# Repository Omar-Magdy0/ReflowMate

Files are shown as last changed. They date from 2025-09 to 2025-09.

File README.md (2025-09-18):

# Reflow Mate

--- 

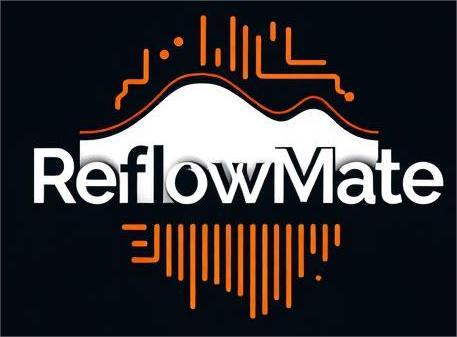
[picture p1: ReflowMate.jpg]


## Your open-source mate to PCB reflowing

#### Idea :
Your companion to pcb repair , assembly and testing , starting with Reflow capabilities...

To start small , grow big. current focus is mainly on providing :
* Digital Soldering iron support
* Hot air gun support
* 3d printable Accessories

#### Added :
* Hardware Core  (AC dimmers and related circuitry, DC Dimmer and related circuitry , Thermocouple interface , NTC interface , Expansion connectors)
#### Planned to be added :
* Fluid and mobile friendly web interface
* TFT LCD interface
* Modern and robust enclosure while keeping it small for mobility 

#### This project is a working in progress and still under testing and development

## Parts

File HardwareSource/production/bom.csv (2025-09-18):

Designator | Footprint | Quantity | Value | LCSC Part #
C1, C3, C5, C7 | 1206 | 4 | 1u-50V | C1848
C10, C9 | 1206 | 2 | 10u | C7432781
C11, C12, C13, C2, C4 | 1206 | 5 | 100n | C24497
D1 | SMA_L4.3-W2.6-LS5.2-RD | 1 | SS34_C8678 | C8678
D10 | DBS_L8.4-W6.4-P5.10-LS10.2-BL | 1 | DB107S_C525738 | C525738
D11, D5, D7, D9 | 1206 | 4 | LED | C965822
D2, D3 | 1206 | 2 | LED RED | C965822
D4, D6, D8 | SOD-123_L2.8-W1.8-LS3.7-RD | 3 | SD103AW_C181204 | C181204
L1 | IND-SMD_L7.1-W6.6_H5.0 | 1 | SMMS0650-680M | C2894721
Q1, Q2 | SOT-23-3_L2.9-W1.3-P0.95-LS2.4-BR | 2 | S9013_C402281 | C402281
Q3, Q4 | TO-220-3_Horizontal_TabDown | 2 | BT136-500 | C916781
Q5, Q6, Q7 | SOT-23_L2.9-W1.3-P1.90-LS2.4-BR | 3 | AO3400_C2938367 | C2938367
R1, R14, R16, R17, R18, R20, R21, R25, R26, R3, R7, R8 | 1206 | 12 | 10k | C17902
R10, R2, R4, R5, R6, R9 | 1206 | 6 | 1k | C2907440
R11, R12 | 1206 | 2 | 360 | C2907486
R13, R15, R19, R27 | 1206 | 4 | 680 | C2907528
R22, R23 | R_Axial_DIN0411_L9.9mm_D3.6mm_P7.62mm_Vertical | 2 | 33k (1W) | C20625284
R24, R28 | 1206 | 2 | 0 | C2907406
R29, R30 | 1206 | 2 | 4.7K | C137262
SW1, SW2 | SW-SMD_L6.0-W3.5-LS8.0 | 2 | TSB008A2526A | C2888456
T1, T2 | DIP-6_L8.5-W6.4-P2.54-LS7.6-BL | 2 | MOC3020M | C86911
U1 | WIFIM-SMD_39P-L25.5-W18.0-P1.27-BL | 1 | ESP32-WROOM-32D | C473012
U2 | SOIC-8_L5.0-W4.0-P1.27-LS6.0-BL | 1 | XL1509-5.0E1 | C61063
U3 | SOT-223-3_TabPin2_NOSILKSCREEN | 1 | AMS1117-3.3 | C347222
U4, U6 | SO-8_L4.9-W3.9-P1.27-LS5.9-BL | 2 | MAX31855KASA+T | C52028
U5 | SOP-4_L6.5-W4.6-P2.54-LS10.3-TL | 1 | EL817S1C(F) | C2912100

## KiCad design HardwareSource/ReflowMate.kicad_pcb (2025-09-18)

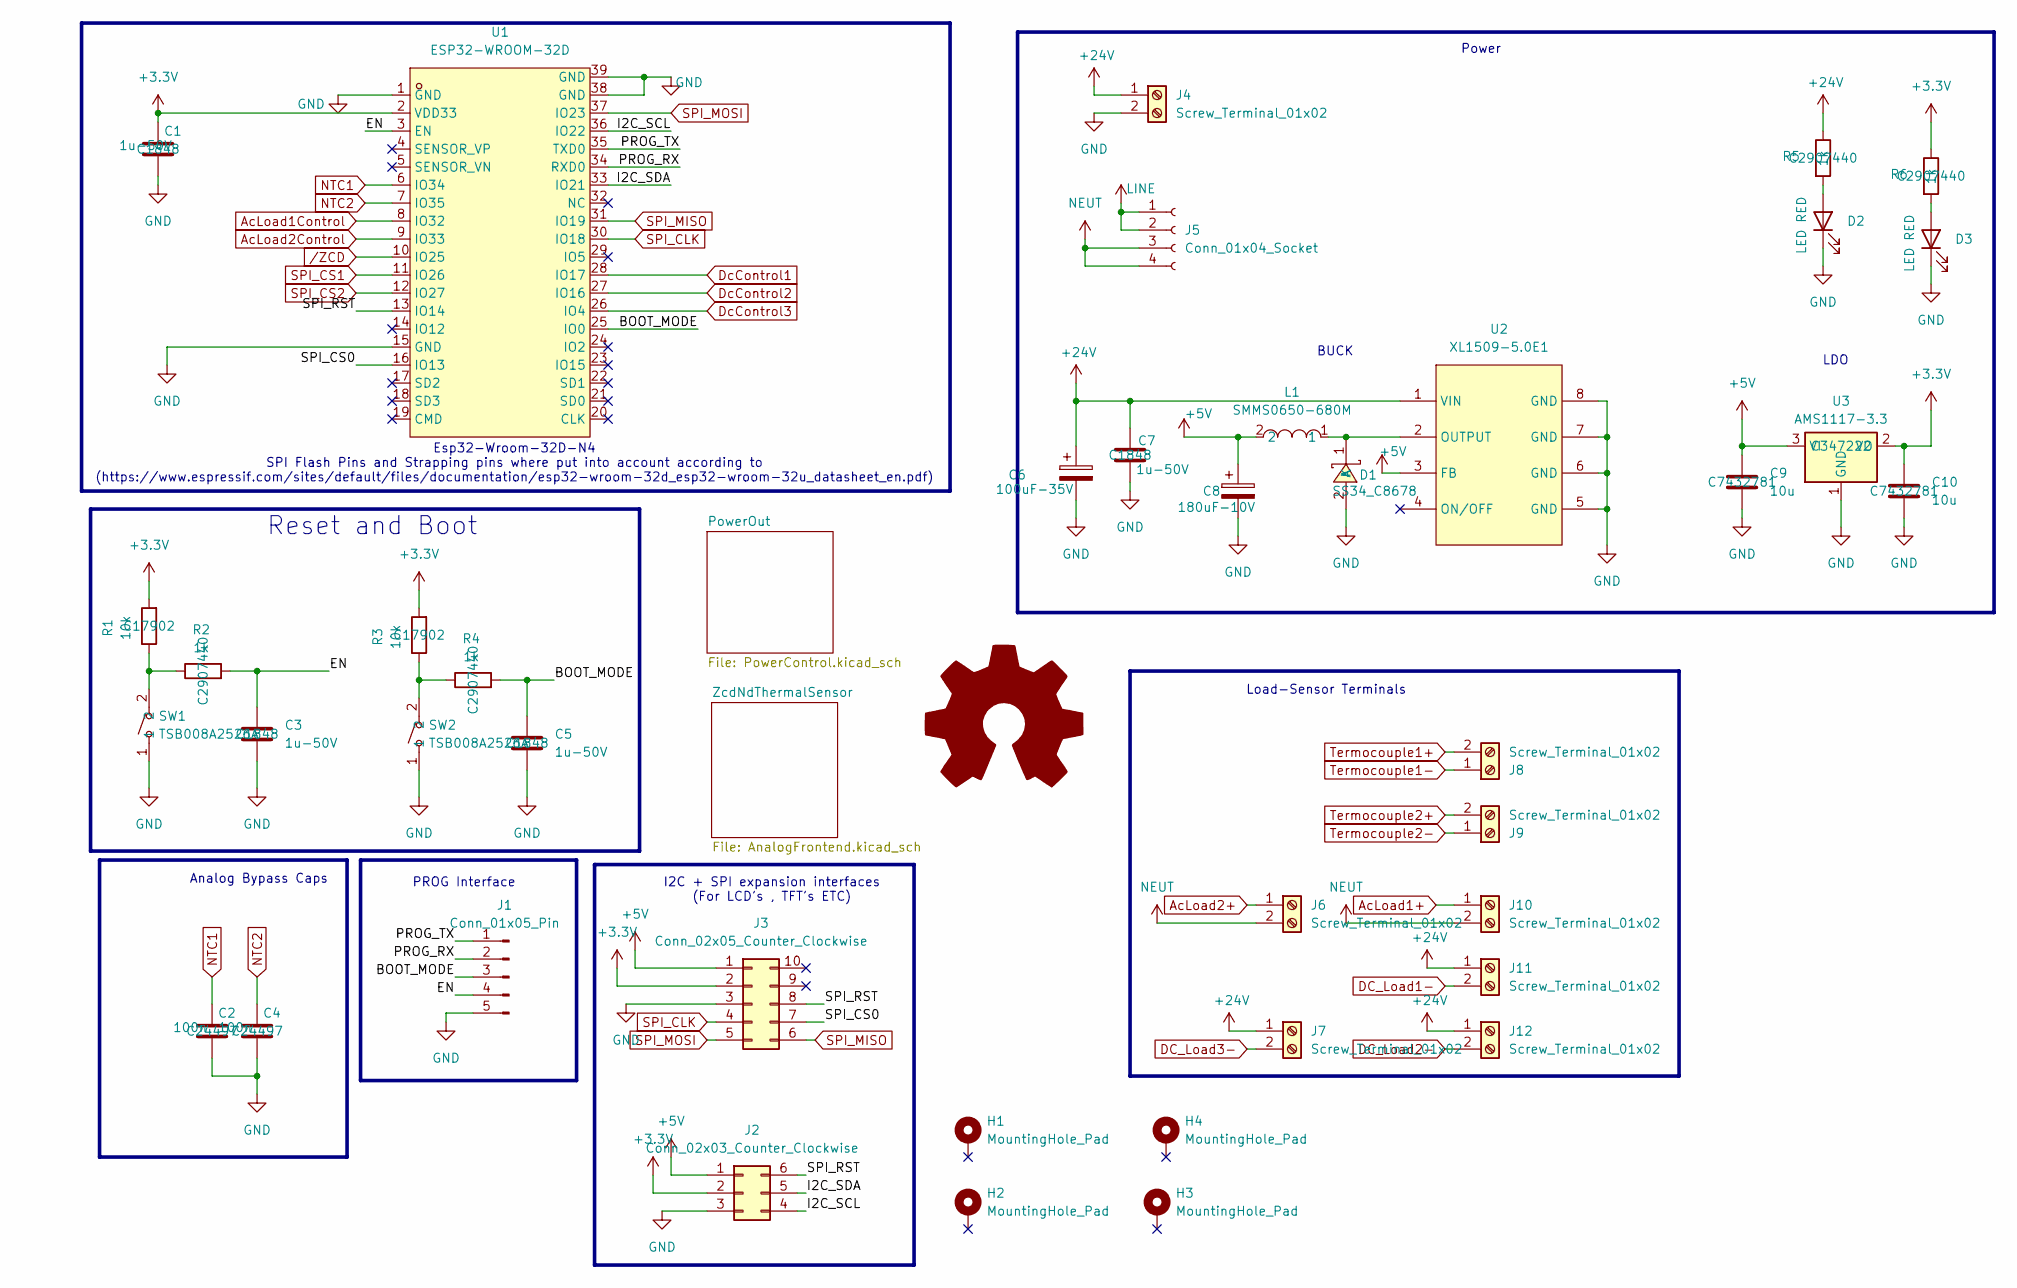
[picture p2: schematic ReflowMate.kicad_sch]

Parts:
C1, C3, C5, C7: 1u-50V; C_1206_3216Metric_Pad1.33x1.80mm_HandSolder; LCSC Part C1848
C2, C4: 100n; C_1206_3216Metric_Pad1.33x1.80mm_HandSolder; LCSC Part C24497
C6: 100uF-35V; CP_Radial_D6.3mm_P2.50mm
C8: 180uF-10V; CP_Radial_D6.3mm_P2.50mm
C9, C10: 10u; C_1206_3216Metric_Pad1.33x1.80mm_HandSolder; LCSC Part C7432781
D1: SS34_C8678; SMA_L4.3-W2.6-LS5.2-RD; LCSC Part C8678
D2, D3: LED RED; LED_1206_3216Metric_Pad1.42x1.75mm_HandSolder; LCSC Part C965822
H1, H2, H3, H4: MountingHole_Pad; MountingHole_3.2mm_M3_Pad_Via
H6: Logo_Open_Hardware_Large; OSHW-Logo2_14.6x12mm_SilkScreen
J1: Conn_01x05_Pin; PinHeader_1x05_P2.54mm_Vertical
J2: Conn_02x03_Counter_Clockwise; IDC-Header_2x03_P2.54mm_Vertical
J3: Conn_02x05_Counter_Clockwise; IDC-Header_2x05_P2.54mm_Vertical
J4, J6, J7, J8, J9, J10, J11, J12: Screw_Terminal_01x02; TerminalBlock_Phoenix_PT-1,5-2-3.5-H_1x02_P3.50mm_Horizontal
J5: Conn_01x04_Socket; SolderWire-1.5sqmm_1x04_P7.8mm_D1.7mm_OD3.9mm
L1: SMMS0650-680M; IND-SMD_L7.1-W6.6_H5.0; LCSC Part C2894721
R1, R3: 10k; R_1206_3216Metric_Pad1.30x1.75mm_HandSolder; LCSC Part C17902
R2, R4, R5, R6: 1k; R_1206_3216Metric_Pad1.30x1.75mm_HandSolder; LCSC Part C2907440
SW1, SW2: TSB008A2526A; SW-SMD_L6.0-W3.5-LS8.0; LCSC Part C2888456
U1: ESP32-WROOM-32D; WIFIM-SMD_39P-L25.5-W18.0-P1.27-BL; LCSC Part C473012
U2: XL1509-5.0E1; SOIC-8_L5.0-W4.0-P1.27-LS6.0-BL; LCSC Part C61063
U3: AMS1117-3.3; SOT-223-3_TabPin2_NOSILKSCREEN; LCSC Part C347222

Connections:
+3.3V: C1.1, C10.1, J2.2, J3.2, R1.2, R3.2, R6.1, U1.2 (VDD33), U3.2 (VO); also elsewhere on the board
+5V: C8.1, C9.1, J2.1, J3.1, L1.2, U2.3 (FB), U3.3 (VI)
+24V: C6.1, C7.1, J4.1, J7.1, J11.1, J12.1, R5.1, U2.1 (VIN); also elsewhere on the board
/BOOT_MODE: C5.1, J1.3, R4.2, U1.25 (IO0)
/EN: C3.1, J1.4, R2.2, U1.3 (EN)
/I2C_SCL: J2.4, U1.36 (IO22)
/I2C_SDA: J2.5, U1.33 (IO21)
/PROG_RX: J1.2, U1.34 (RXD0)
/PROG_TX: J1.1, U1.35 (TXD0)
/SPI_CS0: J3.7, U1.16 (IO13)
/SPI_RST: J2.6, J3.8, U1.13 (IO14)
AcLoad1+: J10.1; also elsewhere on the board
AcLoad1Control: U1.8 (IO32); also elsewhere on the board
AcLoad2+: J6.1; also elsewhere on the board
AcLoad2Control: U1.9 (IO33); also elsewhere on the board
DC_Load1-: J11.2; also elsewhere on the board
DC_Load2-: J12.2; also elsewhere on the board
DC_Load3-: J7.2; also elsewhere on the board
DcControl1: U1.28 (IO17); also elsewhere on the board
DcControl2: U1.27 (IO16); also elsewhere on the board
DcControl3: U1.26 (IO4); also elsewhere on the board
GND: C1.2, C2.2, C3.2, C4.2, C5.2, C6.2, C7.2, C8.2, C9.2, C10.2, D1.2 (A), D2.1 (K), D3.1 (K), J1.5, J2.3, J3.3, J4.2, SW1.1, SW2.1, U1.1 (GND), U1.15 (GND), U1.38 (GND), U1.39 (GND), U2.5 (GND), U2.6 (GND), U2.7 (GND), U2.8 (GND), U3.1 (GND); also elsewhere on the board
LINE: J5.1, J5.2; also elsewhere on the board
NEUT: J5.3, J5.4, J6.2, J10.2; also elsewhere on the board
NTC1: C2.1, U1.6 (IO34); also elsewhere on the board
NTC2: C4.1, U1.7 (IO35); also elsewhere on the board
unnamed: D1.1 (K), L1.1, U2.2 (OUTPUT)
unnamed: D2.2 (A), R5.2
unnamed: D3.2 (A), R6.2
unnamed: R1.1, R2.1, SW1.2
unnamed: R3.1, R4.1, SW2.2
SPI_CLK: J3.4, U1.30 (IO18); also elsewhere on the board
SPI_CS1: U1.11 (IO26); also elsewhere on the board
SPI_CS2: U1.12 (IO27); also elsewhere on the board
SPI_MISO: J3.6, U1.31 (IO19); also elsewhere on the board
SPI_MOSI: J3.5, U1.37 (IO23)
Termocouple1+: J8.2; also elsewhere on the board
Termocouple1-: J8.1; also elsewhere on the board
Termocouple2+: J9.2; also elsewhere on the board
Termocouple2-: J9.1; also elsewhere on the board
/ZCD: U1.10 (IO25); also elsewhere on the board

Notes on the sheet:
Analog Bypass Caps
Esp32-Wroom-32D-N4 SPI Flash Pins and Strapping pins where put into account according to (https://www.espressif.com/sites/default/files/documentation/esp32-wroom-32d_esp32-wroom-32u_datasheet_en.pdf)
Power
LDO
Load-Sensor Terminals
Reset and Boot
BUCK
I2C + SPI expansion interfaces (For LCD's , TFT's ETC)
PROG Interface

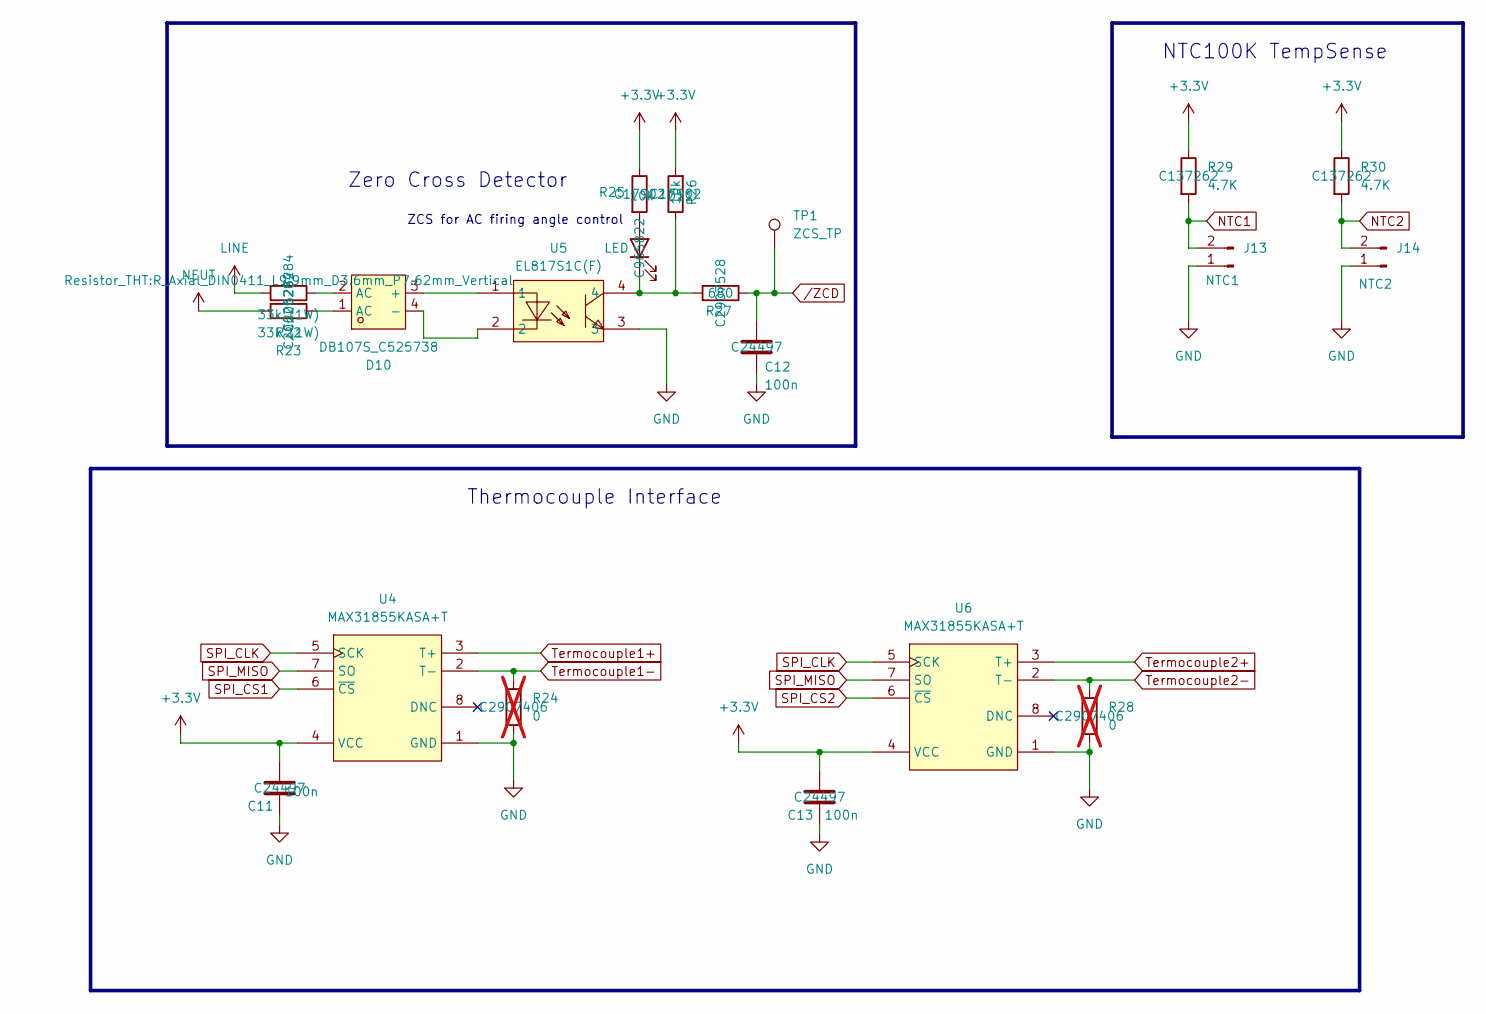
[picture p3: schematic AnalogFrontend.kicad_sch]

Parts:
C11, C12, C13: 100n; C_1206_3216Metric_Pad1.33x1.80mm_HandSolder; LCSC Part C24497
D10: DB107S_C525738; DBS_L8.4-W6.4-P5.10-LS10.2-BL; LCSC Part C525738
D11: LED; LED_1206_3216Metric_Pad1.42x1.75mm_HandSolder; LCSC Part C965822
J13: NTC1; PinHeader_1x02_P2.54mm_Vertical
J14: NTC2; PinHeader_1x02_P2.54mm_Vertical
R22, R23: 33k (1W); R_Axial_DIN0411_L9.9mm_D3.6mm_P7.62mm_Vertical; LCSC Part C20625284
R24, R28: 0; R_1206_3216Metric_Pad1.30x1.75mm_HandSolder; LCSC Part C2907406; not fitted
R25, R26: 10k; R_1206_3216Metric_Pad1.30x1.75mm_HandSolder; LCSC Part C17902
R27: 680; R_1206_3216Metric_Pad1.30x1.75mm_HandSolder; LCSC Part C2907528
R29, R30: 4.7K; R_1206_3216Metric_Pad1.30x1.75mm_HandSolder; LCSC Part C137262
TP1: ZCS_TP; TestPoint_THTPad_2.0x2.0mm_Drill1.0mm
U4, U6: MAX31855KASA+T; SO-8_L4.9-W3.9-P1.27-LS5.9-BL; LCSC Part C52028
U5: EL817S1C(F); SOP-4_L6.5-W4.6-P2.54-LS10.3-TL; LCSC Part C2912100

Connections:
+3.3V: C11.2, C13.2, R25.1, R26.2, R29.1, R30.1, U4.4 (VCC), U6.4 (VCC); also elsewhere on the board
GND: C11.1, C12.2, C13.1, J13.1, J14.1, R24.2, R28.2, U4.1 (GND), U5.3, U6.1 (GND); also elsewhere on the board
LINE: R22.2; also elsewhere on the board
NEUT: R23.2; also elsewhere on the board
NTC1: J13.2, R29.2; also elsewhere on the board
NTC2: J14.2, R30.2; also elsewhere on the board
unnamed: D10.3 (+), U5.1
unnamed: D10.4 (-), U5.2
unnamed: D10.1 (AC), R23.1
unnamed: D10.2 (AC), R22.1
unnamed: D11.2 (A), R25.2
unnamed: D11.1 (K), R26.1, R27.2, U5.4
SPI_CLK: U4.5 (SCK), U6.5 (SCK); also elsewhere on the board
SPI_CS1: U4.6 (~CS); also elsewhere on the board
SPI_CS2: U6.6 (~CS); also elsewhere on the board
SPI_MISO: U4.7 (SO), U6.7 (SO); also elsewhere on the board
Termocouple1+: U4.3 (T+); also elsewhere on the board
Termocouple1-: R24.1, U4.2 (T-); also elsewhere on the board
Termocouple2+: U6.3 (T+); also elsewhere on the board
Termocouple2-: R28.1, U6.2 (T-); also elsewhere on the board
/ZCD: C12.1, R27.1, TP1.1; also elsewhere on the board

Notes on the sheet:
Zero Cross Detector
Thermocouple Interface
NTC100K TempSense
ZCS for AC firing angle control

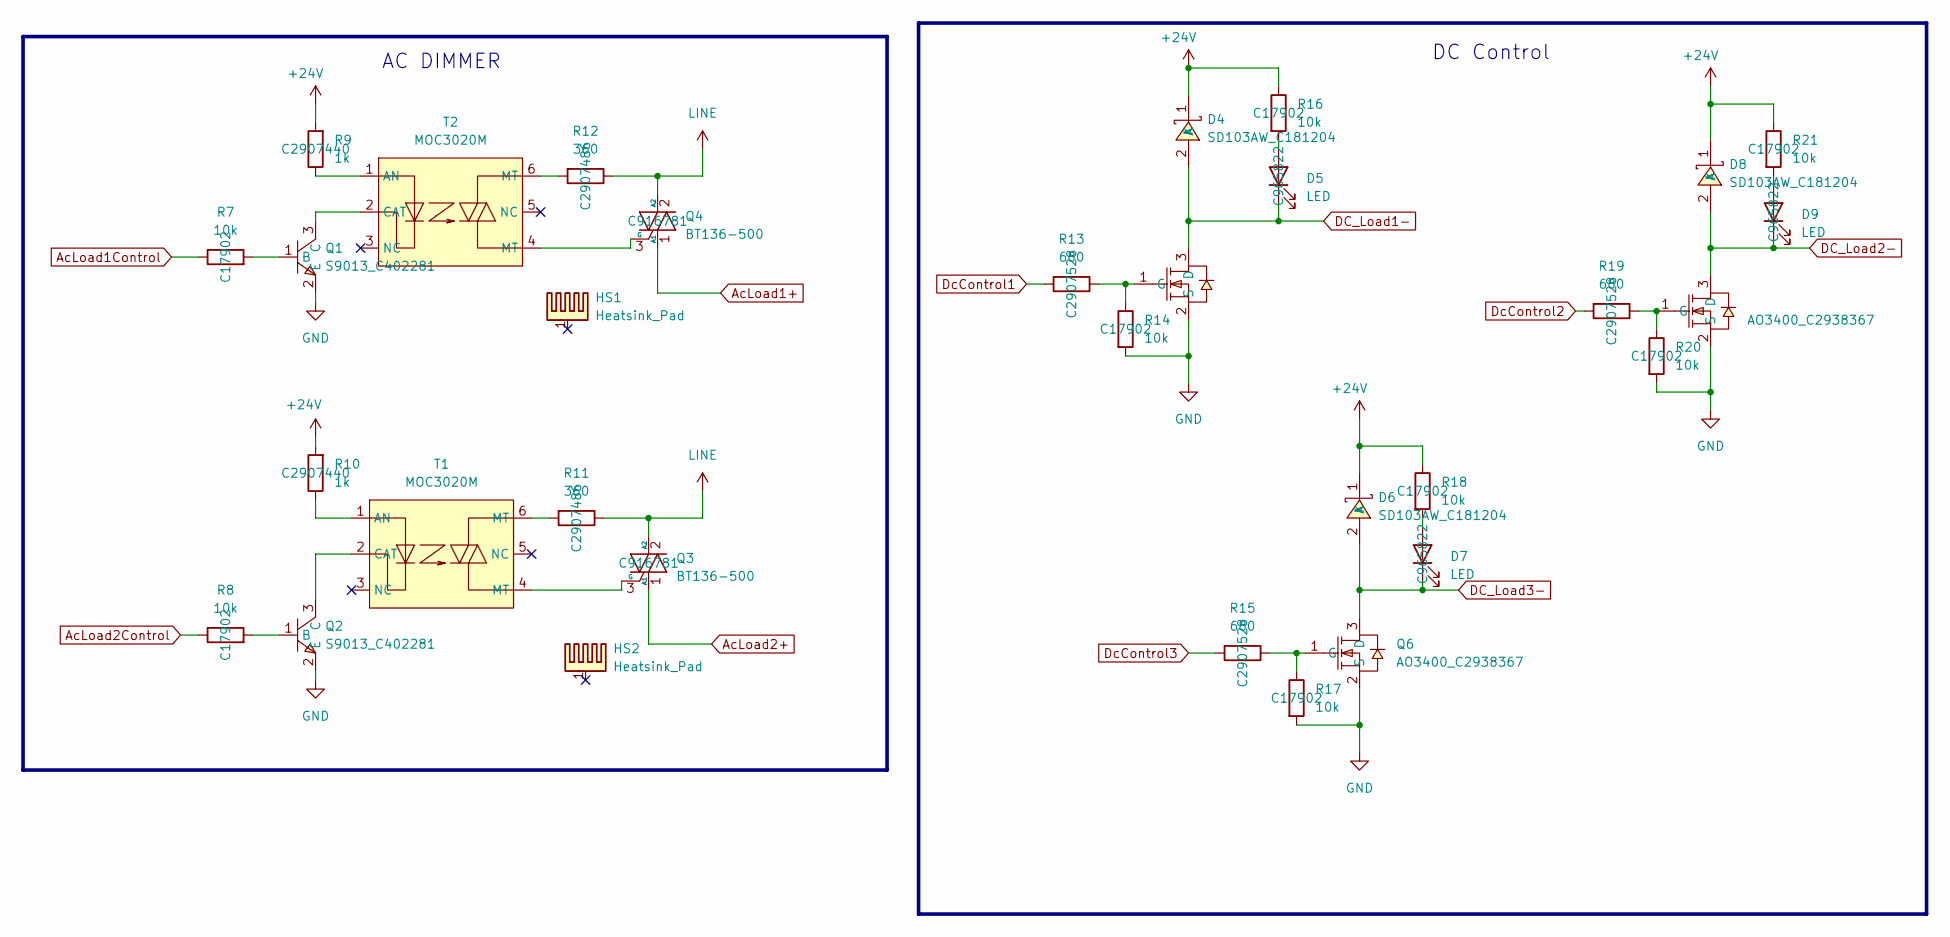
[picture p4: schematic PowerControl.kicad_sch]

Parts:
D4, D6, D8: SD103AW_C181204; SOD-123_L2.8-W1.8-LS3.7-RD; LCSC Part C181204
D5, D7, D9: LED; LED_1206_3216Metric_Pad1.42x1.75mm_HandSolder; LCSC Part C965822
HS1, HS2: Heatsink_Pad; TO-220 HeatPad
Q1, Q2: S9013_C402281; SOT-23-3_L2.9-W1.3-P0.95-LS2.4-BR; LCSC Part C402281
Q3, Q4: BT136-500; TO-220-3_Horizontal_TabDown; LCSC Part C916781
Q5, Q6, Q7: AO3400_C2938367; SOT-23_L2.9-W1.3-P1.90-LS2.4-BR; LCSC Part C2938367
R7, R8, R14, R16, R17, R18, R20, R21: 10k; R_1206_3216Metric_Pad1.30x1.75mm_HandSolder; LCSC Part C17902
R9, R10: 1k; R_1206_3216Metric_Pad1.30x1.75mm_HandSolder; LCSC Part C2907440
R11, R12: 360; R_1206_3216Metric_Pad1.30x1.75mm_HandSolder; LCSC Part C2907486
R13, R15, R19: 680; R_1206_3216Metric_Pad1.30x1.75mm_HandSolder; LCSC Part C2907528
T1, T2: MOC3020M; DIP-6_L8.5-W6.4-P2.54-LS7.6-BL; LCSC Part C86911

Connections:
+24V: D4.1 (K), D6.1 (K), D8.1 (K), R9.2, R10.2, R16.1, R18.1, R21.1; also elsewhere on the board
AcLoad1+: Q4.1 (A1); also elsewhere on the board
AcLoad1Control: R7.1; also elsewhere on the board
AcLoad2+: Q3.1 (A1); also elsewhere on the board
AcLoad2Control: R8.1; also elsewhere on the board
DC_Load1-: D4.2 (A), D5.1 (K), Q5.3 (D); also elsewhere on the board
DC_Load2-: D8.2 (A), D9.1 (K), Q7.3 (D); also elsewhere on the board
DC_Load3-: D6.2 (A), D7.1 (K), Q6.3 (D); also elsewhere on the board
DcControl1: R13.2; also elsewhere on the board
DcControl2: R19.2; also elsewhere on the board
DcControl3: R15.2; also elsewhere on the board
GND: Q1.2 (E), Q2.2 (E), Q5.2 (S), Q6.2 (S), Q7.2 (S), R14.2, R17.2, R20.2; also elsewhere on the board
LINE: Q3.2 (A2), Q4.2 (A2), R11.1, R12.1; also elsewhere on the board
unnamed: D5.2 (A), R16.2
unnamed: D7.2 (A), R18.2
unnamed: D9.2 (A), R21.2
unnamed: Q1.1 (B), R7.2
unnamed: Q1.3 (C), T2.2 (CAT)
unnamed: Q2.1 (B), R8.2
unnamed: Q2.3 (C), T1.2 (CAT)
unnamed: Q3.3 (G), T1.4 (MT)
unnamed: Q4.3 (G), T2.4 (MT)
unnamed: Q5.1 (G), R13.1, R14.1
unnamed: Q6.1 (G), R15.1, R17.1
unnamed: Q7.1 (G), R19.1, R20.1
unnamed: R11.2, T1.6 (MT)
unnamed: R12.2, T2.6 (MT)
unnamed: R10.1, T1.1 (AN)
unnamed: R9.1, T2.1 (AN)

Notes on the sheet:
DC Control
AC DIMMER

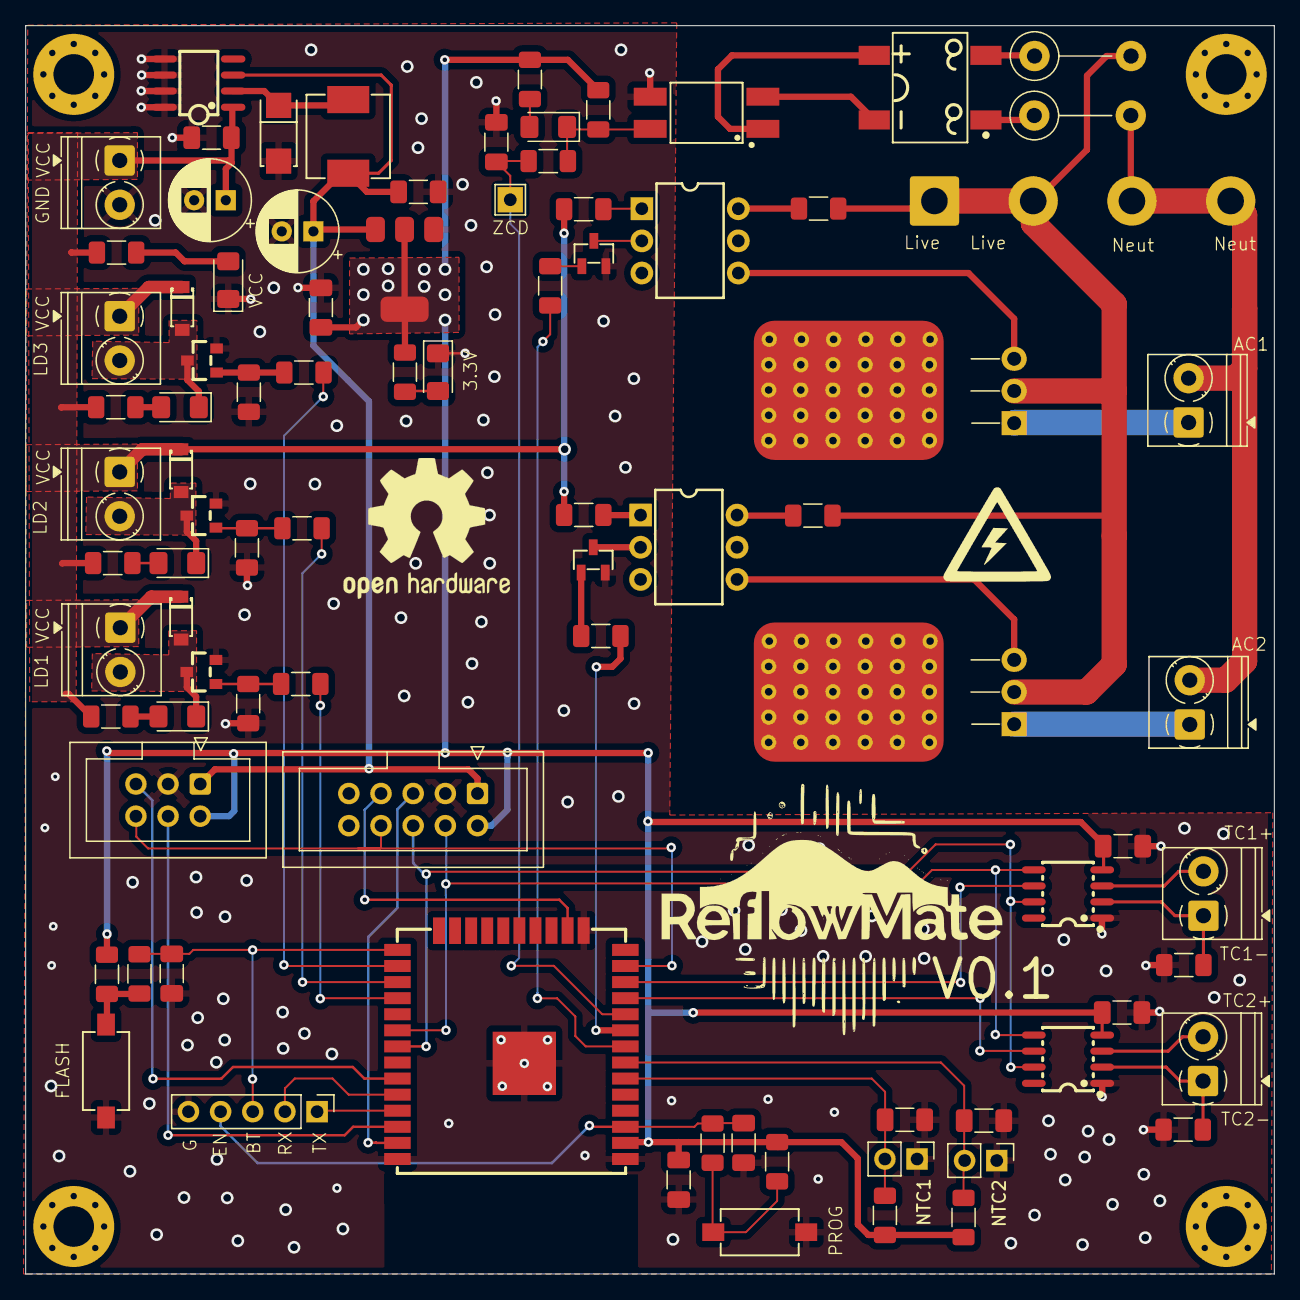
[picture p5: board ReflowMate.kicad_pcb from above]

Board: 2 copper layers, 98.6 x 98.6 mm, 94 parts (1 on the bottom side), 63 nets.

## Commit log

2025-08-03 Finished Routing, Finished Schematic
    Yet to add , solderMask
    [AnalogFrontend.kicad_sch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]
2025-08-04 Fixed Silkscreen, Added production files
    [AnalogFrontend.kicad_sch, ExtraDopeSolderingStation.kicad_pcb, ExtraDopeSolderingStation.kicad_sch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]
2025-09-18 Key Fixes and upgrade to V0.1
    Design reliance on dedicated thermocouple interface chip instead of calibrating adc and differential amplifier ; Neater routing ; Logos ; High voltage spacing for AC part
    [AnalogFrontend.kicad_sch, DcPowerOut.kicad_sch, ExtraDopeSolderingStation.kicad_pcb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]
2025-09-18 ReadMe , Reorder Repo
    [AnalogFrontend.kicad_sch, DcPowerOut.kicad_sch, PowerControl.kicad_sch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]
